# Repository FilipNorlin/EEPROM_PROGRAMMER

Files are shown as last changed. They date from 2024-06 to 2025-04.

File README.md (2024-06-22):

# EEPROM_PROGRAMMER

## Diagram

```mermaid
flowchart TD
    BAT(Battery) --> V_REG(Voltage Regulator)
    V_REG --> Protection(Input Protection)
    USB(USB C) --> Protection
    Protection --> MCU{MCU}
    MCU --> LCD(LCD Display)
    MCU --> Input(Input Controls)
    MCU --> SD(SD Card Reader)
    MCU --> Logic(Logic)
    Logic --> LED(Data LEDs)
    Logic --> EEPROM(EEPROM)

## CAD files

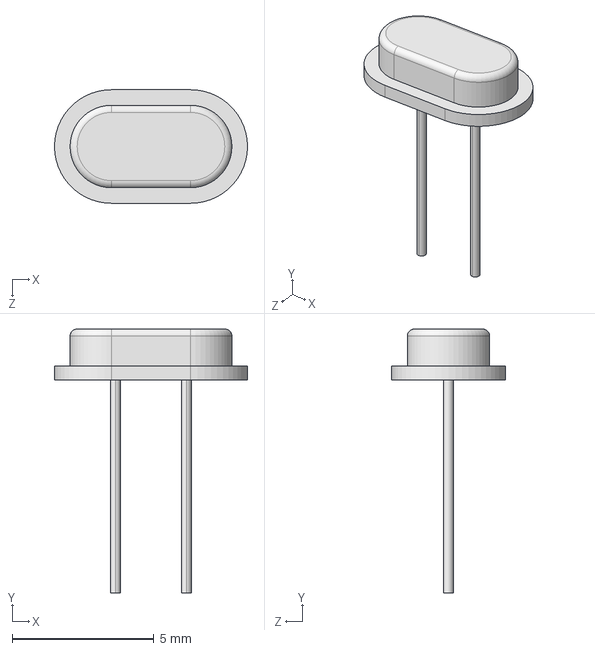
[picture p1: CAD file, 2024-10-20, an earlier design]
Rev_1/ECAD/board/3d_library/EEPROM_PROGRAMMER/Crystal.STEP
6.80 x 9.30 x 4.00 mm

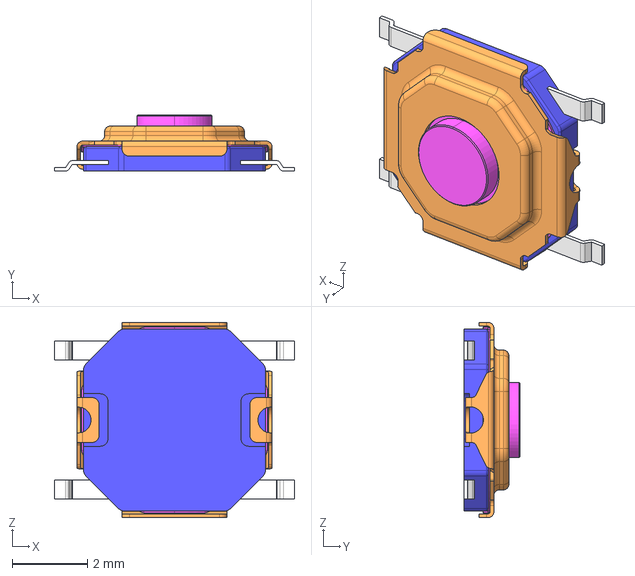
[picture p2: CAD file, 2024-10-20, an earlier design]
Rev_1/ECAD/board/3d_library/EEPROM_PROGRAMMER/SMD-BUTTON.step
6.40 x 1.50 x 5.20 mm

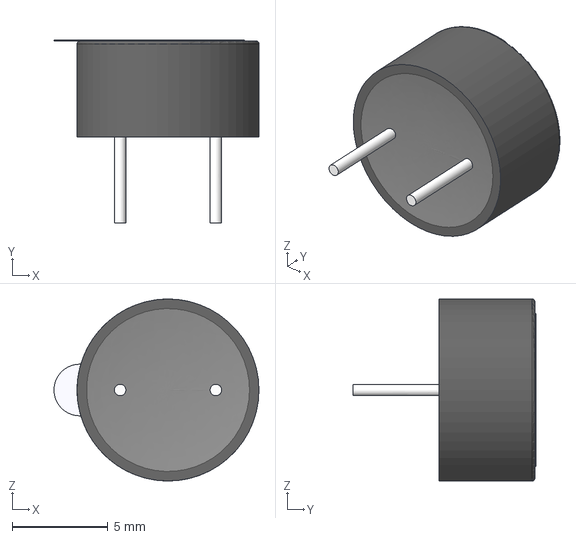
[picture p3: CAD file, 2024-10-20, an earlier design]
Rev_1/ECAD/board/3d_library/EEPROM_PROGRAMMER/Summer.STEP
10.7 x 9.55 x 9.50 mm

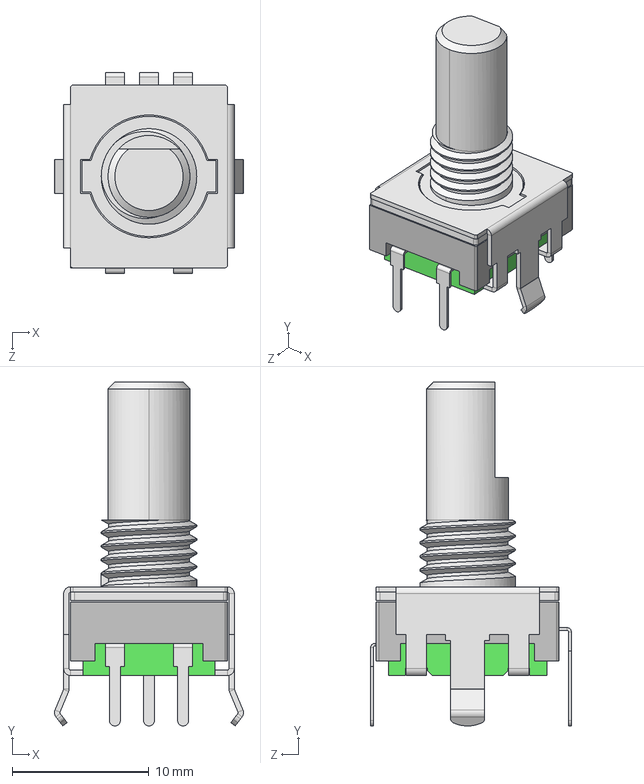
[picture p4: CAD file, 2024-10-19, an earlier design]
Rev_1/ECAD/board/3d_library/EEPROM_PROGRAMMER/PEC11R-4215F-S0024.STEP
13.9 x 25.2 x 14.7 mm

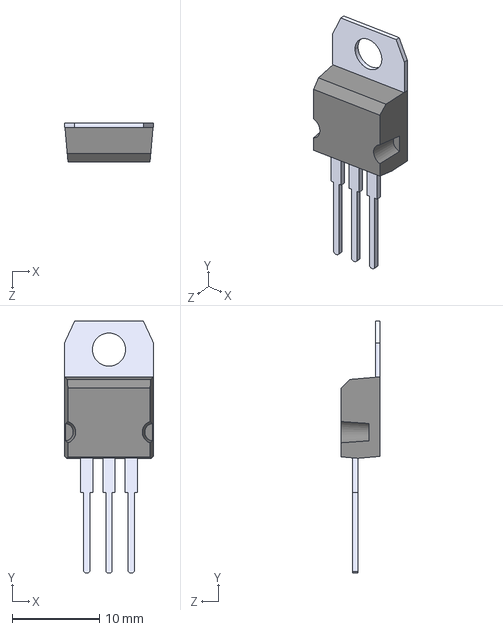
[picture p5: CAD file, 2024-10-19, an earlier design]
Rev_1/ECAD/board/3d_library/EEPROM_PROGRAMMER/L7805ABV.STEP
10.2 x 28.9 x 4.50 mm

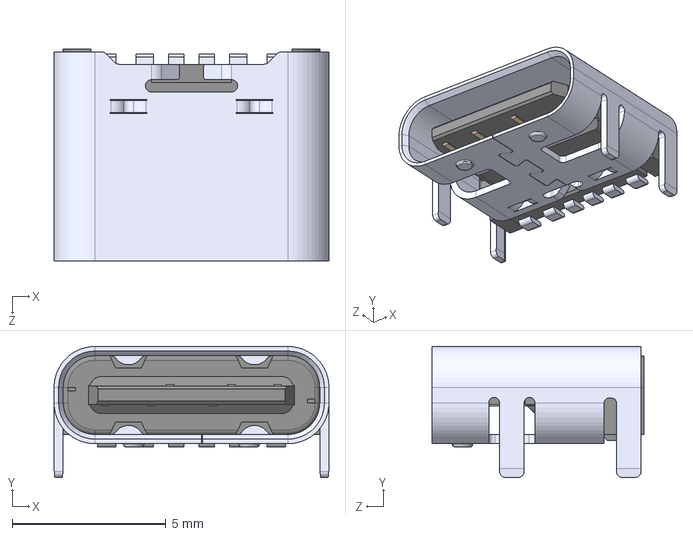
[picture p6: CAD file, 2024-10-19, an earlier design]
Rev_1/ECAD/board/3d_library/EEPROM_PROGRAMMER/USB_C.STEP
8.94 x 4.26 x 6.90 mm

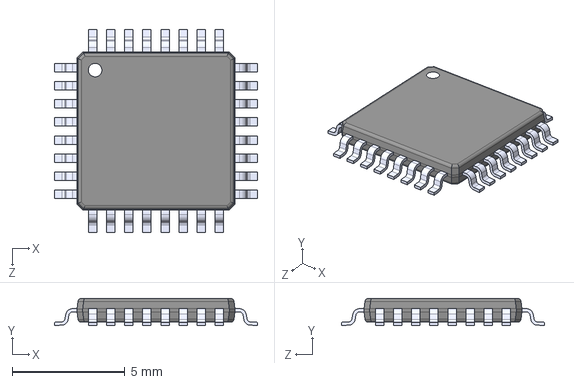
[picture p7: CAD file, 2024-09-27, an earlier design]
Rev_1/ECAD/board/3d_library/EEPROM_PROGRAMMER/ATMega328P-AU.STEP
9.00 x 1.20 x 9.00 mm

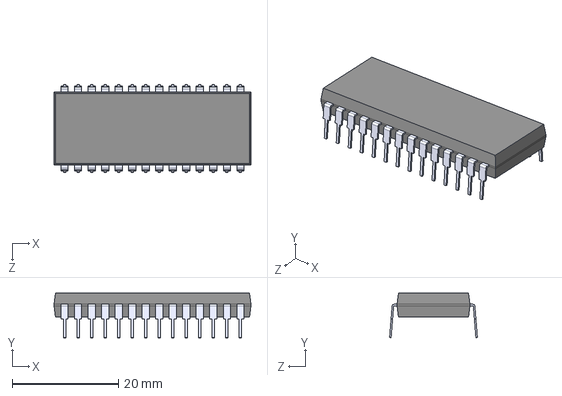
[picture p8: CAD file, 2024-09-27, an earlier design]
Rev_1/ECAD/board/3d_library/EEPROM_PROGRAMMER/AT28C64B-15PU.STEP
37.0 x 8.38 x 16.5 mm

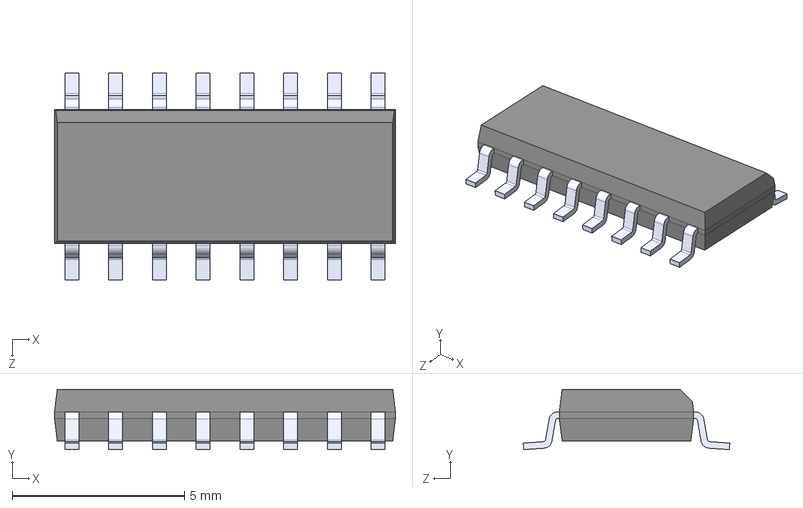
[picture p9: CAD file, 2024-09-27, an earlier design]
Rev_1/ECAD/board/3d_library/EEPROM_PROGRAMMER/4076B.STEP
9.90 x 1.75 x 6.00 mm

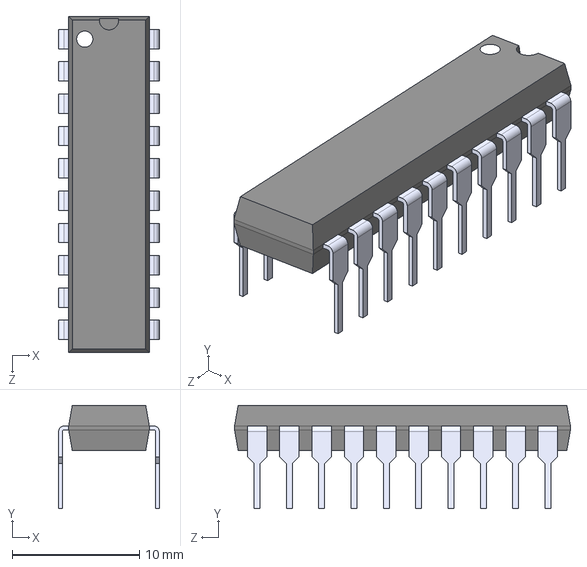
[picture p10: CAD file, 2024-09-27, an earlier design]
Rev_1/ECAD/board/3d_library/EEPROM_PROGRAMMER/74HC245N,652.STEP
7.91 x 8.13 x 26.4 mm

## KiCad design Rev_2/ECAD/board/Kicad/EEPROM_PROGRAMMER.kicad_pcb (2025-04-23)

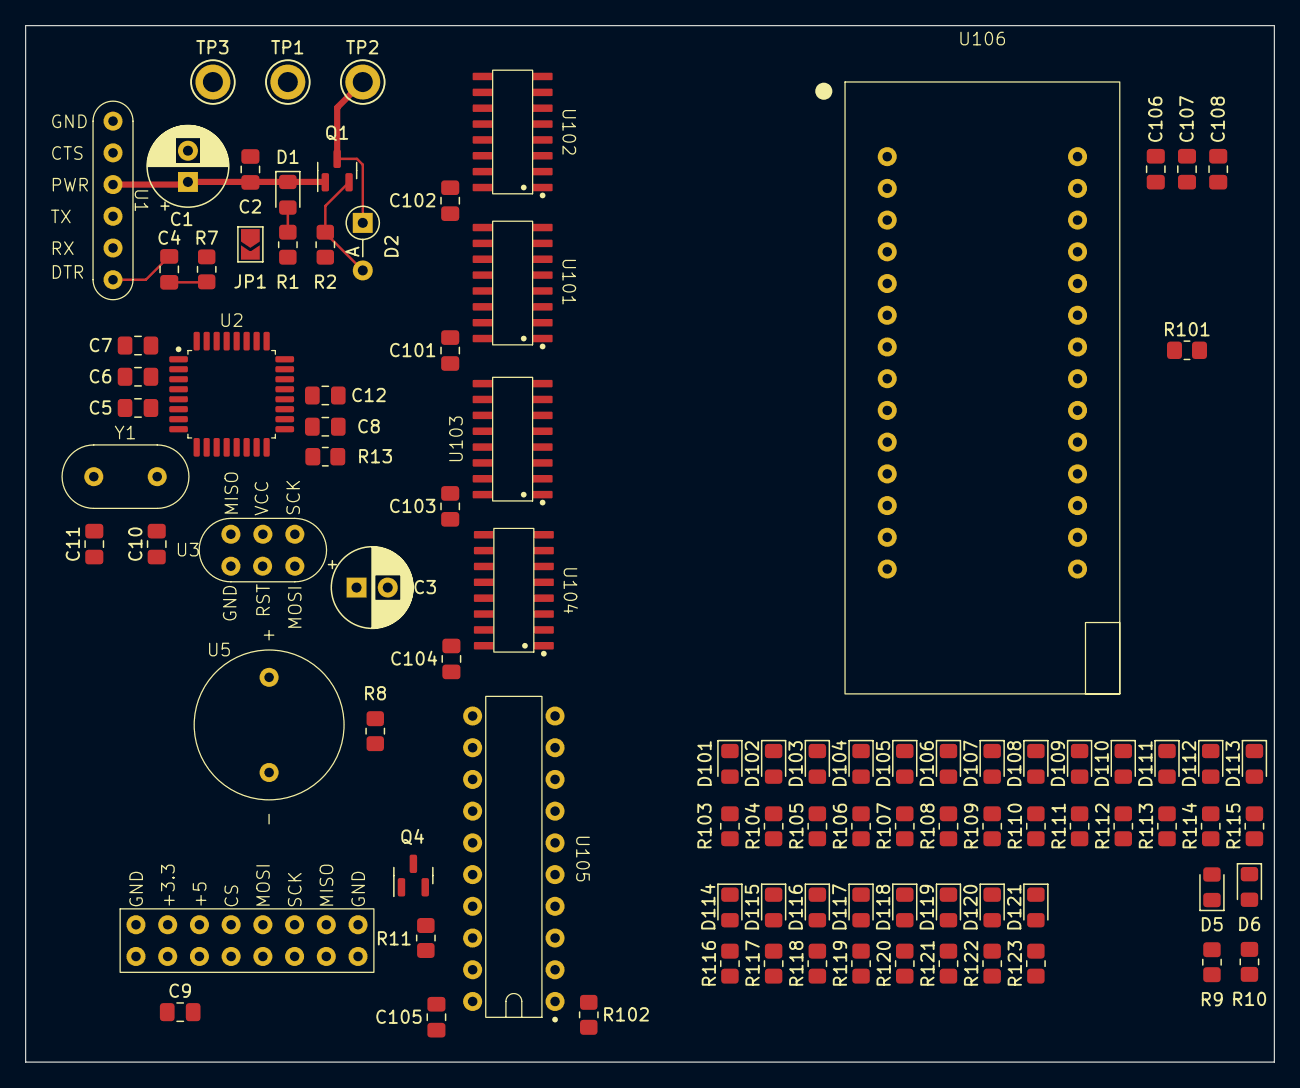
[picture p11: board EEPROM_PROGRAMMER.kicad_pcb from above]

Board: 4 copper layers, 100.0 x 83.0 mm, 94 parts (0 on the bottom side), 78 nets.

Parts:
C1, C3: 100u; CP_Radial_D6.3mm_P2.50mm
C2, C4, C6, C7, C8, C9, C12, C101, C102, C103, C104, C105, C108: 100n; C_0805_2012Metric_Pad1.18x1.45mm_HandSolder
C5, C106: 4u7; C_0805_2012Metric_Pad1.18x1.45mm_HandSolder
C10, C11: 22p; C_0805_2012Metric_Pad1.18x1.45mm_HandSolder
C107: 1u; C_0805_2012Metric_Pad1.18x1.45mm_HandSolder
D1: RED; LED_0805_2012Metric_Pad1.15x1.40mm_HandSolder
D2: 9V; D_DO-35_SOD27_P3.81mm_Vertical_AnodeUp
D5: READ; LED_0805_2012Metric_Pad1.15x1.40mm_HandSolder
D6: WRITE; LED_0805_2012Metric_Pad1.15x1.40mm_HandSolder
D101, D102, D103, D104, D105, D106, D107, D108, D109, D110, D111, D112, D113: BLUE; LED_0805_2012Metric_Pad1.15x1.40mm_HandSolder
D114, D115, D116, D117, D118, D119, D120, D121: GREEN; LED_0805_2012Metric_Pad1.15x1.40mm_HandSolder
JP1: Jumper; SolderJumper-2_P1.3mm_Open_TrianglePad1.0x1.5mm
Q1: PMOS; SOT-23
Q4: NPN; SOT-23
R1, R2, R9, R10, R103, R104, R105, R106, R107, R108, R109, R110, R111, R112, R113, R114, R115, R116, R117, R118, R119, R120, R121, R122, R123: 4k7; R_0805_2012Metric_Pad1.20x1.40mm_HandSolder
R7, R8, R11, R13, R101, R102: 10k; R_0805_2012Metric_Pad1.20x1.40mm_HandSolder
TP1: PWR; TestPoint_Keystone_5005-5009_Compact
TP2: 5V; TestPoint_Keystone_5005-5009_Compact
TP3: GND; TestPoint_Keystone_5005-5009_Compact
U1: FT232RL
U2: ATMega328P-AU
U3: ICSP
U4: SD_CARD_READER
U5: SUM; Summer
U101, U102, U103, U104: 4076B
U105: 74HC245
U106: AT28C64B-15PU
Y1: 16MHz; Crystal

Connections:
+5V: C5.2, C6.2, C7.2, C8.2, C9.2, C101.1, C102.1, C103.1, C104.1, C105.1, C106.1, C107.1, C108.1, D2.1 (K), JP1.2 (B), Q1.3 (S), R7.1, R13.1, R101.1, TP2.1, U2.4 (VCC), U2.6 (VCC), U2.18 (AVCC), U4.3 (5V), U101.16 (VDD), U102.16 (VDD), U103.16 (VDD), U104.16 (VDD), U105.20 (VCC), U106.28 (VCC)
/D4: U2.2 ((T0)PD4), U106.27 (WE*)
/D5: U2.9 ((T1)PD5), U103.9 (G1), U103.10 (G2), U104.9 (G1), U104.10 (G2)
/D6: U2.10 ((AIN0)D6), U101.9 (G1), U101.10 (G2), U102.9 (G1), U102.10 (G2)
/D7: U2.11 ((AIN1)PD7), U101.7 (CLOCK), U102.7 (CLOCK), U103.7 (CLOCK), U104.7 (CLOCK)
/D8: U2.12 ((ICP)PB0), U101.13 (D2), U103.13 (D2), U105.12 (B6)
/D9: U2.13 ((OC1)PB1), U101.14 (D1), U103.14 (D1), U105.11 (B7)
/D10/SELECT: R11.2, R13.2, U2.14 ((SS)PB2), U4.4 (#CS)
/D11/MOSI: R10.2, U2.15 ((MOSI)PB3), U3.4 (MOSI), U4.5 (MOSI)
/D12/MISO: R9.2, U2.16 ((MISO)PB4), U3.1 (MISO), U4.7 (MISO)
/D13/SCK: R8.2, U2.17 ((SCK)PB5), U3.3 (SCK), U4.6 (SCK)
/D14: U2.23 ((ADC0)PC0), U102.11 (D4), U104.11 (D4), U105.18 (B0)
/D15: U2.24 ((ADC1)PC1), U102.12 (D3), U104.12 (D3), U105.17 (B1)
/D16: U2.25 ((ADC2)PC2), U102.13 (D2), U104.13 (D2), U105.16 (B2)
/D17: U2.26 ((ADC3)PC3), U102.14 (D1), U104.14 (D1), U105.15 (B3)
/D18: U2.27 ((ADC4)PC4), U101.11 (D4), U103.11 (D4), U105.14 (B4)
/D19: U2.28 ((ADC5)PC5), U101.12 (D3), U103.12 (D3), U105.13 (B5)
/DTR: C4.1, U1.6 (DTR)
/EEPROM_LOGIC/A0: R103.1, U101.3 (Q1), U106.10 (A0)
/EEPROM_LOGIC/A1: R104.1, U101.4 (Q2), U106.9 (A1)
/EEPROM_LOGIC/A2: R105.1, U101.5 (Q3), U106.8 (A2)
/EEPROM_LOGIC/A3: R106.1, U101.6 (Q4), U106.7 (A3)
/EEPROM_LOGIC/A4: R107.1, U102.3 (Q1), U106.6 (A4)
/EEPROM_LOGIC/A5: R108.1, U102.4 (Q2), U106.5 (A5)
/EEPROM_LOGIC/A6: R109.1, U102.5 (Q3), U106.4 (A6)
/EEPROM_LOGIC/A7: R110.1, U102.6 (Q4), U106.3 (A7)
/EEPROM_LOGIC/A8: R111.1, U103.3 (Q1), U106.25 (A8)
/EEPROM_LOGIC/A9: R112.1, U103.4 (Q2), U106.24 (A9)
/EEPROM_LOGIC/A10: R113.1, U103.5 (Q3), U106.21 (A10)
/EEPROM_LOGIC/A11: R114.1, U103.6 (Q4), U106.23 (A11)
/EEPROM_LOGIC/A12: R115.1, U104.3 (Q1), U106.2 (A12)
/EEPROM_LOGIC/BUFFER_DIR: R102.2, U104.5 (Q3), U105.1 (DIR)
/EEPROM_LOGIC/BUFFER_OE: U104.6 (Q4), U105.19 (OE)
/EEPROM_LOGIC/EEPROM_OE: R101.2, U104.4 (Q2), U106.22 (OE*)
/EEPROM_LOGIC/I/O0: R116.1, U105.9 (A7), U106.11 (I/O0)
/EEPROM_LOGIC/I/O1: R117.1, U105.8 (A6), U106.12 (I/O1)
/EEPROM_LOGIC/I/O2: R118.1, U105.7 (A5), U106.13 (I/O2)
/EEPROM_LOGIC/I/O3: R119.1, U105.6 (A4), U106.15 (I/O3)
/EEPROM_LOGIC/I/O4: R120.1, U105.5 (A3), U106.16 (I/O4)
/EEPROM_LOGIC/I/O5: R121.1, U105.4 (A2), U106.17 (I/O5)
/EEPROM_LOGIC/I/O6: R122.1, U105.3 (A1), U106.18 (I/O6)
/EEPROM_LOGIC/I/O7: R123.1, U105.2 (A0), U106.19 (I/O7)
/POLARITY_PROTECTION: C1.1, C2.1, C3.1, D1.1 (K), JP1.1 (A), Q1.1 (D), TP1.1, U1.3 (PWR), U3.2 (VCC)
/RESET: C4.2, R7.2, U2.29 (RESET), U3.5 (RST)
/RX-TX: U1.5 (RX), U2.31 ((TXD)PD1)
/SELECT_GND: D5.1 (K), D6.1 (K), Q4.1 (C), U5.2 (-)
/TX-RX: U1.4 (TX), U2.30 ((RXD)PD0)
/VGS: D2.2 (A), Q1.2 (G), R2.1
/XTAL1: C11.2, U2.7 (XTAL1), Y1.1
/XTAL2: C10.2, U2.8 (XTAL2), Y1.2
GND: C1.2, C2.2, C3.2, C5.1, C6.1, C7.1, C8.1, C9.1, C10.1, C11.1, C12.1, C101.2, C102.2, C103.2, C104.2, C105.2, C106.2, C107.2, C108.2, D101.1 (K), D102.1 (K), D103.1 (K), D104.1 (K), D105.1 (K), D106.1 (K), D107.1 (K), D108.1 (K), D109.1 (K), D110.1 (K), D111.1 (K), D112.1 (K), D113.1 (K), D114.1 (K), D115.1 (K), D116.1 (K), D117.1 (K), D118.1 (K), D119.1 (K), D120.1 (K), D121.1 (K), Q4.3 (E), R1.2, R2.2, R102.1, TP3.1, U1.1 (GND), U2.3 (GND), U2.5 (GND), U2.21 (AGND), U3.6 (GND), U4.1 (GND), U101.1 (M), U101.2 (N), U101.8 (VSS), U101.15 (Reset), U102.1 (M), U102.2 (N), U102.8 (VSS), U102.15 (Reset), U103.1 (M), U103.2 (N), U103.8 (VSS), U103.15 (Reset), U104.1 (M), U104.2 (N), U104.8 (VSS), U104.15 (Reset), U105.10 (GND), U106.14 (GND), U106.20 (CE*)
unnamed: D1.2 (A), R1.1
unnamed: D5.2 (A), R9.1
unnamed: D6.2 (A), R10.1
unnamed: D101.2 (A), R103.2
unnamed: D102.2 (A), R104.2
unnamed: D103.2 (A), R105.2
unnamed: D104.2 (A), R106.2
unnamed: D105.2 (A), R107.2
unnamed: D106.2 (A), R108.2
unnamed: D107.2 (A), R109.2
unnamed: D108.2 (A), R110.2
unnamed: D109.2 (A), R111.2
unnamed: D110.2 (A), R112.2
unnamed: D111.2 (A), R113.2
unnamed: D112.2 (A), R114.2
unnamed: D113.2 (A), R115.2
unnamed: D114.2 (A), R116.2
unnamed: D115.2 (A), R117.2
unnamed: D116.2 (A), R118.2
unnamed: D117.2 (A), R119.2
unnamed: D118.2 (A), R120.2
unnamed: D119.2 (A), R121.2
unnamed: D120.2 (A), R122.2
unnamed: D121.2 (A), R123.2
unnamed: Q4.2 (B), R11.1
unnamed: C12.2, U2.20 (AREF)
unnamed: R8.1, U5.1 (+)

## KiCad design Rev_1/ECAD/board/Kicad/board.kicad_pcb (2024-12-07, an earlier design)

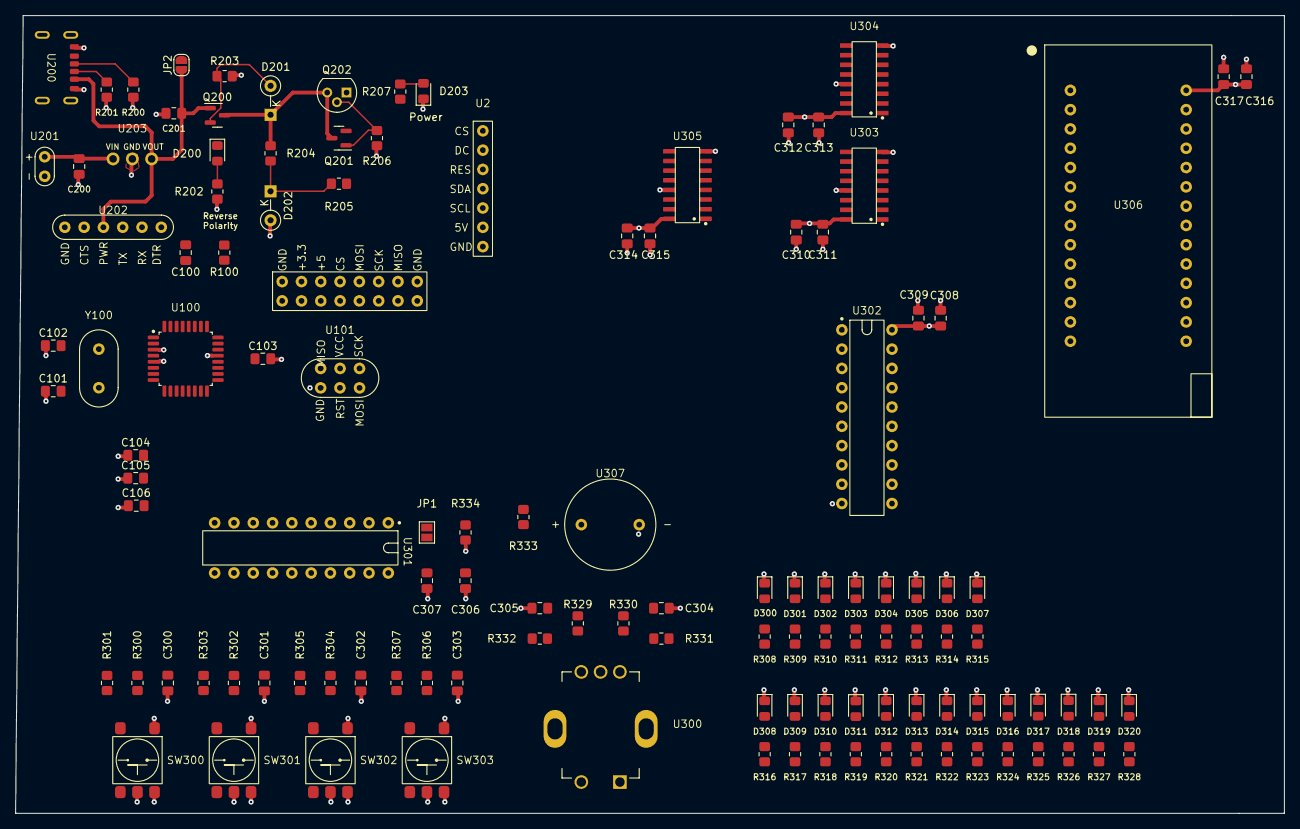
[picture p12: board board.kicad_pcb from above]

Board: 4 copper layers, 167.0 x 105.0 mm, 122 parts (0 on the bottom side), 101 nets.

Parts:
C100, C103, C201, C304, C305: 100n; C_0805_2012Metric_Pad1.18x1.45mm_HandSolder
C101, C102: 22p; C_0805_2012Metric_Pad1.18x1.45mm_HandSolder
C104, C106, C300, C301, C302, C303, C306, C308, C310, C312, C314, C316: 1u; C_0805_2012Metric_Pad1.18x1.45mm_HandSolder
C105: 4u7; C_0805_2012Metric_Pad1.18x1.45mm_HandSolder
C200: 330n; C_0805_2012Metric_Pad1.18x1.45mm_HandSolder
C307, C309, C311, C313, C315, C317: 10n; C_0805_2012Metric_Pad1.18x1.45mm_HandSolder
D200: RED; LED_0805_2012Metric_Pad1.15x1.40mm_HandSolder
D201: 9V; D_DO-35_SOD27_P3.81mm_Vertical_KathodeUp
D202: 5V6; D_DO-35_SOD27_P3.81mm_Vertical_KathodeUp
D203, D301, D302, D303, D304, D305, D306, D307: GREEN; LED_0805_2012Metric_Pad1.15x1.40mm_HandSolder
D300, D308, D309, D310, D311, D312, D313, D314, D315, D316, D317, D318, D319, D320: BLUE; LED_0805_2012Metric_Pad1.15x1.40mm_HandSolder
JP1: SolderJumper_2_Open; SolderJumper-2_P1.3mm_Open_Pad1.0x1.5mm
JP2: SolderJumper_2_Open; SolderJumper-2_P1.3mm_Open_RoundedPad1.0x1.5mm
Q200: PMOS; SOT-23
Q201: PNP; SOT-23
Q202: PNP; TO-92
R100, R301, R303, R305, R307, R329, R330, R331, R332, R333, R334: 10k; R_0805_2012Metric_Pad1.20x1.40mm_HandSolder
R200, R201, R202, R203, R204, R206, R207, R308, R309, R310, R311, R312, R313, R314, R315, R316, R317, R318, R319, R320, R321, R322, R323, R324, R325, R326, R327, R328: 5k1; R_0805_2012Metric_Pad1.20x1.40mm_HandSolder
R205, R300, R302, R304, R306: 1k; R_0805_2012Metric_Pad1.20x1.40mm_HandSolder
SW300, SW301, SW302, SW303: 6x6; SMD_Button
U1: SD_CARD_READER
U2: LCD OLED; LCD_OLED
U100: ATMega328P-AU
U101: ICSP
U200: USB_C_6PIN
U201: Battery_Connectors
U202: FT232RL
U203: L7805ABV
U300: Rotary_Encoder
U301, U302: 74HC245
U303, U304, U305: 74HC595; 74HC595D
U306: AT28C64B-15PU
U307: Summer
Y100: 16MHZ; Crystal

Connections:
+5V: C104.2, C105.2, C106.2, C306.2, C307.2, C308.2, C309.2, C310.2, C311.2, C312.2, C313.2, C314.2, C315.2, C316.2, C317.2, JP1.2 (B), JP2.2 (B), Q202.1 (C), R100.1, R207.1, R301.1, R303.1, R305.1, R307.1, R331.2, R332.2, U1.3 (5V), U2.2 (5V), U100.4 (VCC), U100.6 (VCC), U100.18 (AVCC), U101.2 (VCC), U300.4 (VCC), U301.20 (VCC), U302.20 (VCC), U303.10 (SRCLR*), U303.16 (VCC), U304.10 (SRCLR*), U304.16 (VCC), U305.10 (SRCLR*), U305.16 (VCC), U306.28 (VCC)
/DC: U2.6 (DC), U100.13 ((OC1)PB1)
/Data Logic/A0: R316.2, U303.1 (QB), U306.10 (A0)
/Data Logic/A1: R317.2, U303.2 (QC), U306.9 (A1)
/Data Logic/A2: R318.2, U303.3 (QD), U306.8 (A2)
/Data Logic/A3: R319.2, U303.4 (QE), U306.7 (A3)
/Data Logic/A4: R320.2, U303.5 (QF), U306.6 (A4)
/Data Logic/A5: R321.2, U303.6 (QG), U306.5 (A5)
/Data Logic/A6: R322.2, U303.7 (QH), U306.4 (A6)
/Data Logic/A7: R323.2, U304.1 (QB), U306.3 (A7)
/Data Logic/A8: R324.2, U304.2 (QC), U306.25 (A8)
/Data Logic/A9: R325.2, U304.3 (QD), U306.24 (A9)
/Data Logic/A10: R326.2, U304.4 (QE), U306.21 (A10)
/Data Logic/A11: R327.2, U304.5 (QF), U306.23 (A11)
/Data Logic/A12: R328.2, U304.6 (QG), U306.2 (A12)
/Data Logic/BUTTON_1: C300.2, R300.2, R301.2, U301.13 (B5)
/Data Logic/BUTTON_2: C301.2, R302.2, R303.2, U301.14 (B4)
/Data Logic/BUTTON_3: C302.2, R304.2, R305.2, U301.15 (B3)
/Data Logic/BUTTON_4: C303.2, R306.2, R307.2, U301.16 (B2)
/Data Logic/D0: R308.2, U302.18 (B0), U306.11 (I/O0)
/Data Logic/D1: R309.2, U302.17 (B1), U306.12 (I/O1)
/Data Logic/D2: R310.2, U302.16 (B2), U306.13 (I/O2)
/Data Logic/D3: R311.2, U302.15 (B3), U306.15 (I/O3)
/Data Logic/D4: R312.2, U302.14 (B4), U306.16 (I/O4)
/Data Logic/D5: R313.2, U302.13 (B5), U306.17 (I/O5)
/Data Logic/D6: R314.2, U302.12 (B6), U306.18 (I/O6)
/Data Logic/D7: R315.2, U302.11 (B7), U306.19 (I/O7)
/Data Logic/DATA_BUFFER_DIR: U302.1 (DIR), U305.4 (QE)
/Data Logic/DATA_BUFFER_OE: U302.19 (OE), U305.5 (QF)
/Data Logic/EEPROM_OE*: U305.3 (QD), U306.22 (OE*)
/Data Logic/INPUT_BUFFER_OE: U301.19 (OE), U305.2 (QC)
/Data Logic/ROT_A: R330.1, R331.1, U300.2 (A)
/Data Logic/ROT_A_INPT: C304.2, R330.2, U301.17 (B1)
/Data Logic/ROT_B: R329.1, R332.1, U300.3 (B)
/Data Logic/ROT_B_INPT: C305.2, R329.2, U301.18 (B0)
/Data Logic/SER_CASCADE_1: U303.9 (QH'), U304.14 (SER)
/Data Logic/SER_CASCADE_2: U304.9 (QH'), U305.14 (SER)
/Data Logic/Summer: R333.2, U307.1 (+)
/Data Logic/Summer_CL: R333.1, U305.1 (QB)
/EEPROM_WE*: U100.28 ((ADC5)PC5), U306.27 (WE*)
/I/O0: U100.25 ((ADC2)PC2), U301.2 (A0), U302.2 (A0)
/I/O1: U100.26 ((ADC3)PC3), U301.3 (A1), U302.3 (A1)
/I/O2: U100.32 ((INT0)PD2), U301.4 (A2), U302.4 (A2)
/I/O3: U100.1 ((INT1)PD3), U301.5 (A3), U302.5 (A3)
/I/O4: U100.2 ((T0)PD4), U301.6 (A4), U302.6 (A4)
/I/O5: U100.9 ((T1)PD5), U301.7 (A5), U302.7 (A5)
/I/O6: U100.10 ((AIN0)D6), U301.8 (A6), U302.8 (A6)
/I/O7: U100.11 ((AIN1)PD7), U301.9 (A7), U302.9 (A7)
/MCU/AREF: C103.1, U100.20 (AREF)
/MCU/DTR: C100.1, U202.6 (DTR)
/MCU/RESET: C100.2, R100.2, U100.29 (RESET), U101.5 (RST)
/MCU/RX/TX: U100.31 ((TXD)PD1), U202.5 (RX)
/MCU/TX/RX: U100.30 ((RXD)PD0), U202.4 (TX)
/MCU/XTAL1: C102.2, U100.7 (XTAL1), Y100.1
/MCU/XTAL2: C101.2, U100.8 (XTAL2), Y100.2
/MISO/SDA: U1.7 (MISO), U2.4 (SDA), U100.16 ((MISO)PB4), U101.1 (MISO)
/MOSI/RES: U1.5 (MOSI), U2.5 (RES), U100.15 ((MOSI)PB3), U101.4 (MOSI)
/OLED_CS: U2.7 (CS), U100.12 ((ICP)PB0)
/SCK/SCL: U1.6 (SCK), U2.3 (SCL), U100.17 ((SCK)PB5), U101.3 (SCK)
/SD_CS: U1.4 (CS), U100.14 ((SS)PB2)
/SHIFT_RCLK: U100.27 ((ADC4)PC4), U303.12 (RCLK), U304.12 (RCLK), U305.12 (RCLK)
/SHIFT_SER: U100.24 ((ADC1)PC1), U303.14 (SER)
/SHIFT_SRCLK: U100.23 ((ADC0)PC0), U303.11 (SRCLK), U304.11 (SRCLK), U305.11 (SRCLK)
/Voltage Input/5V_REGULATED: C201.2, D200.1 (K), JP2.1 (A), Q200.1 (D), U200.2 (VBUS), U200.5 (VBUS), U202.3 (PWR), U203.3 (VOUT)
/Voltage Input/BATTERY_INPUT: C200.2, U201.1 (+), U203.1 (VIN)
/Voltage Input/POLARITY_PROTECTED: D201.1 (K), Q200.3 (S), Q201.3 (E), Q202.3 (E), R204.1
/Voltage Input/USB_CC1: R200.1, U200.3 (CC1)
/Voltage Input/USB_CC2: R201.1, U200.4 (CC2)
/Voltage Input/VGS: D201.2 (A), Q200.2 (G), R203.1
GND: C101.1, C102.1, C103.2, C104.1, C105.1, C106.1, C200.1, C201.1, C300.1, C301.1, C302.1, C303.1, C304.1, C305.1, C306.1, C307.1, C308.1, C309.1, C310.1, C311.1, C312.1, C313.1, C314.1, C315.1, C316.1, C317.1, D202.2 (A), D203.1 (K), D300.1 (K), D301.1 (K), D302.1 (K), D303.1 (K), D304.1 (K), D305.1 (K), D306.1 (K), D307.1 (K), D308.1 (K), D309.1 (K), D310.1 (K), D311.1 (K), D312.1 (K), D313.1 (K), D314.1 (K), D315.1 (K), D316.1 (K), D317.1 (K), D318.1 (K), D319.1 (K), D320.1 (K), R200.2, R201.2, R202.2, R203.2, R206.2, R334.2, SW300.1, SW300.3 (GND), SW301.1, SW301.3 (GND), SW302.1, SW302.3 (GND), SW303.1, SW303.3 (GND), U1.1 (GND), U2.1 (GND), U100.3 (GND), U100.5 (GND), U100.21 (AGND), U101.6 (GND), U200.1 (GND), U200.6 (GND), U201.2 (-), U202.1 (GND), U203.2 (GND), U300.1 (GND), U301.10 (GND), U301.11 (B7), U301.12 (B6), U302.10 (GND), U303.8 (GND), U303.13 (OE*), U304.8 (GND), U304.13 (OE*), U305.8 (GND), U305.13 (OE*), U306.14 (GND), U306.20 (CE*), U307.2 (-)
unnamed: D200.2 (A), R202.1
unnamed: D202.1 (K), R204.2, R205.1
unnamed: D203.2 (A), R207.2
unnamed: D300.2 (A), R308.1
unnamed: D301.2 (A), R309.1
unnamed: D302.2 (A), R310.1
unnamed: D303.2 (A), R311.1
unnamed: D304.2 (A), R312.1
unnamed: D305.2 (A), R313.1
unnamed: D306.2 (A), R314.1
unnamed: D307.2 (A), R315.1
unnamed: D308.2 (A), R316.1
unnamed: D309.2 (A), R317.1
unnamed: D310.2 (A), R318.1
unnamed: D311.2 (A), R319.1
unnamed: D312.2 (A), R320.1
unnamed: D313.2 (A), R321.1
unnamed: D314.2 (A), R322.1
unnamed: D315.2 (A), R323.1
unnamed: D316.2 (A), R324.1
unnamed: D317.2 (A), R325.1
unnamed: D318.2 (A), R326.1
unnamed: D319.2 (A), R327.1
unnamed: D320.2 (A), R328.1
unnamed: JP1.1 (A), R334.1, U301.1 (DIR)
unnamed: Q201.2 (B), R205.2
unnamed: Q201.1 (C), Q202.2 (B), R206.1
unnamed: R300.1, SW300.2
unnamed: R302.1, SW301.2
unnamed: R304.1, SW302.2
unnamed: R306.1, SW303.2

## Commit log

2024-05-30 Migrate to Mac
    [board.kicad_pcb, board.kicad_sch]
2024-06-09 Remove files specified in .gitignore
    [board.kicad_pcb, board.kicad_sch, mcu.kicad_sch]
2024-06-09 Auto commit by interactive_git.py
    [board.kicad_pcb, board.kicad_sch, mcu.kicad_sch]
2024-06-09 Added MCU sketch
    [mcu.kicad_sch]
2024-06-09 Added USB Power circiut
    [board.kicad_sch, mcu.kicad_sch]
2024-06-22 Added power unit, and started on the logic block
    [board.kicad_sch, data_logic.kicad_sch, mcu.kicad_sch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]
2024-06-29 Updated net-name on Data Logic sheet
    [board.kicad_pcb, board.kicad_sch, data_logic.kicad_sch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]
2024-06-29 Added Bus aswell as data logic for the eeprom
    [data_logic.kicad_sch, mcu.kicad_sch]
2024-06-30 Added Rotary encoder Symbol
2024-06-30 Added Rotary encoder and buttons to the Input Buffer
    [board.kicad_sch, data_logic.kicad_sch, mcu.kicad_sch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]
2024-07-25 Updated gitignore
    [data_logic.kicad_sch, mcu.kicad_sch, voltage_input.kicad_sch]
2024-09-18 Updating Bus wiring
    [data_logic.kicad_sch, mcu.kicad_sch]
2024-09-25 Updated Symbol library´and added SD Card Reader to schematic
    [board.kicad_sch, data_logic.kicad_sch, mcu.kicad_sch]
2024-09-25 Added 74HC595 footprint
2024-09-26 Added footprint 74HC245 and 4076B
2024-09-26 Removed unwanted footprint
2024-09-27 Added marker for pin 1 on 74HC245
2024-09-27 Linked some of the symbols to its footprint
2024-09-27 Added 3d models to footprint
    [4076B.STEP, 74HC245N,652.STEP, 74HC595D.STEP]
2024-09-27 Added Zif socket
    [AT28C64B-15PU.STEP]
2024-09-27 Added Atmega328P-AU Footprint and 3d model
    [ATMega328P-AU.STEP]
2024-09-27 Added Connectors
2024-10-16 Removed I2C Display and added an SPI Display instead
    [board.kicad_sch, mcu.kicad_sch]
2024-10-16 Add fp-lib-table to track
2024-10-18 Changes current limiting resistors for LEDS to 5k1 ohms
    [data_logic.kicad_sch, mcu.kicad_sch]
2024-10-19 Added Usb-C Footprint
    [USB_C.STEP]
2024-10-19 Added 7805ABV and SD_CARD_READER
    [L7805ABV.STEP]
2024-10-19 Updated Data Logic sheet
    [data_logic.kicad_sch, mcu.kicad_sch]
2024-10-19 Added Rotary Encoder
    [PEC11R-4215F-S0024.STEP]
2024-10-20 Changed from 4-bit registers to shift registers
    [Crystal.STEP, SMD-BUTTON.step, Summer.STEP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]
2024-10-21 Created a pcb file and added labels to footprints
    [board.kicad_pcb, data_logic.kicad_sch]
2024-10-21 Added Bypass Capacitors
    [data_logic.kicad_sch]
2024-10-21 Updated Bypass Capacitors Label
    [data_logic.kicad_sch]
2024-10-21 Set up PCB configurations
2024-10-21 Made a ruf idea of the input protection on the pcb
    [board.kicad_pcb, voltage_input.kicad_sch]
2024-11-16 Sorted most of the individual circuitri, time to start putting it all togheter
    [board.kicad_pcb]
2024-11-16 Layed out the input power circuit
    [board.kicad_pcb]
2024-11-16 Made changes to the wiring in the shcematic to make it easier to route on the pcb, U305
    [board.kicad_pcb, data_logic.kicad_sch]
2024-11-16 Made some progress on the pcb
    [board.kicad_pcb, data_logic.kicad_sch]
2024-11-16 Most of the things are put to its place, LED indicators still needs some configuration, and som testpoints should be added!
    [board.kicad_pcb]
2024-11-27 Changed the footprint on D201 and D202 to DO-35_SOD27
    [voltage_input.kicad_sch]
2024-12-07 Updated Zif socket to right dimensions
2024-12-07 Everything finished, can start routing
    [board.kicad_pcb, voltage_input.kicad_sch]
2024-12-07 Added cutout to the pcb
    [board.kicad_pcb]
2024-12-07 Most of the GND vias are in place and the power section is mostly done
    [board.kicad_pcb]
2025-03-12 Copied libraries from Rev1 to Rev2
    [data_logic.kicad_sch]
2025-03-12 Added data and voltage input with FTDI
    [EEPROM_PROGRAMMER.kicad_pcb, EEPROM_PROGRAMMER.kicad_sch]
2025-03-12 Added Reverse Polarity Protection and Overvoltage Portection
    [EEPROM_PROGRAMMER.kicad_sch]
2025-03-13 Added Atmega328 to the schematic
    [EEPROM_PROGRAMMER.kicad_sch]
2025-03-13 Added SD-Card Reader to schematic
    [EEPROM_PROGRAMMER.kicad_sch]
2025-03-13 Adde Summer, Read-LED, Write-LED
    [EEPROM_PROGRAMMER.kicad_sch]
2025-03-19 Added registers for the EEPROM
    [EEPROM_PROGRAMMER.kicad_sch, eeprom_logic.kicad_sch]
2025-03-20 Added a sheet page for EEPROM_LOGIC
    [eeprom_logic.kicad_sch]
2025-03-20 Finished most of EEPROM LOGIC
    [EEPROM_PROGRAMMER.kicad_sch, eeprom_logic.kicad_sch]
2025-03-20 Atmega to logic wiring completed
    [EEPROM_PROGRAMMER.kicad_sch]
2025-03-21 Added Bypass capacitors aswell as pullup resistors
    [EEPROM_PROGRAMMER.kicad_sch, eeprom_logic.kicad_sch]
2025-04-22 Removed overvoltage protection for now
    [EEPROM_PROGRAMMER.kicad_sch]
2025-04-22 Ready for PCB-Design
    [EEPROM_PROGRAMMER.kicad_sch, eeprom_logic.kicad_sch]
2025-04-22 Set up bases of board configurations
    [EEPROM_PROGRAMMER.kicad_pcb, EEPROM_PROGRAMMER.kicad_sch]
2025-04-22 Added missing 3D-models aswell as fixed wrong footprints
    [EEPROM_PROGRAMMER.kicad_pcb, EEPROM_PROGRAMMER.kicad_sch, eeprom_logic.kicad_sch]
2025-04-23 Done with inital layout
    [EEPROM_PROGRAMMER.kicad_pcb, EEPROM_PROGRAMMER.kicad_sch, eeprom_logic.kicad_sch]
